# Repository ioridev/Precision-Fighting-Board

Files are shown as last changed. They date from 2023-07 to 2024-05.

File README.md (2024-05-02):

# [Precision-Fighting-Board](https://github.com/ioridev/Precision-Fighting-Board)
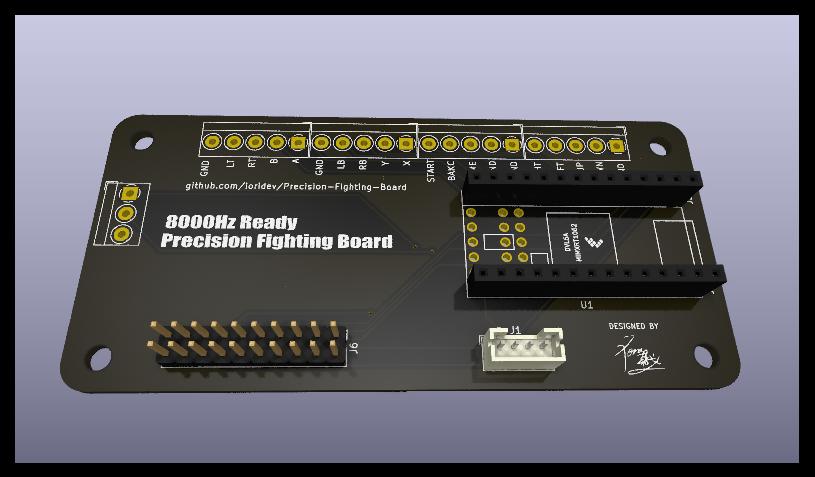
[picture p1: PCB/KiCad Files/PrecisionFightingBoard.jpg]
board


We all need to use this board in 20XX.  
[Discussions](https://github.com/ioridev/Precision-Fighting-Board/discussions)  
## Description

This project aims to develop the fastest game controller by utilizing the power of [Teensy 4.0](https://www.pjrc.com/store/teensy40.html). We strive to achieve a polling rate of 8000Hz, delivering unparalleled responsiveness for an immersive gaming experience.

## Where to Buy
Booth (https://iori-giken.booth.pm/)  
Available for purchase on Booth. Buying from this shop directly supports the developers. For international customers, shipping outside of Japan is possible using address forwarding services like Buyee and Tenso.  


[https://iori-giken.booth.pm/](https://iori-giken.booth.pm/)

## Features

- High-speed USB communication using [Teensy 4.0](https://www.pjrc.com/store/teensy40.html)
- Targeting an impressive 8000Hz polling rate
- Precise and instantaneous input response
- X-input support
- No waiting time for debounce

## Installation
Open the PrecisionFightingBoard.TEENSY40.hex file in [Teensyduino 1.53](https://www.pjrc.com/teensy/td_158/TeensyduinoInstall.exe) and write to [Teensy 4.0](https://www.pjrc.com/store/teensy40.html).　
| Pin Number | Button |
|---|---|
| 0 | Up |
| 1 | Down |
| 2 | Left |
| 3 | Right |
| 4 | Home |
| 5 | Back |
| 6 | Start |
| 7 | Y |
| 8 | X |
| 9 | RB |
| 10 | LB |
| 11 | A |
| 12 | B |
| 14 | RT |
| 15 | LT |
| 18 | L3 |
| 19 | R3 |


### Tips
Not good at soldering or making wires?  
Some models are equipped with pins from the beginning, so you can skip this complicated process by using this type of wire and wire for Brook.  
[Teensy 4.0 Pins](https://www.pjrc.com/store/teensy40_pins.html)

  
  
  


One GND with a pin is missing, so it must be branched with a breadboard or similar.　 

Or you can purchase Breakout Board on Amazon.  
  
[Breakout Board for Teensy 4.0](https://www.amazon.com/dp/B0C5SXFTC1?_encoding=UTF8&psc=1&ref_=cm_sw_r_cp_ud_dp_3P4ZTVVE18NE8B7TW8SG)

## Setting Up the Development Environment
Install Arduino IDE 1.8.13 and Teensyduino 1.53.

Clone this repository and copy the x-input/ArduinoXinput_Teensy/teensy directory to C:\Program Files (x86)\Arduino\hardware.

Open PrecisionFightingBoard.ino with the Arduino IDE, go to Tools, change the USB Type to XInput, and then upload it to the Teensy 4.0.

## Benchmark
### Polling rate test results 
I caught the continuous X-input button loop in my Python program and confirmed that it was around 0.125 ms.  
  
The program used for the test is in Precision-Fighting-Board/x-input/tester and anyone can try it out.

### Comparison with PicoBoard
tester/gamepad_response_time_comparison.py  
Gamepad 1 is a Precision-Fighting-Board.  
Gamepad 2 is a gp2040-ce  

  

### Comparison with Brook PS4+ Audio Fighting Board
Gamepad 1 is a Precision-Fighting-Board.  
Gamepad 2 is a Brook AFB  


### Use with WingmanFGC　
This is a test on a PC, but when used with WingmanFGC.  
Gamepad 1 is a Precision-Fighting-Board with WingmanFGC.  
Gamepad 2 is a gp2040-ce  
  
Good results with input lag of up to 5 ms.　　　

## Contributing

Contributions are welcome! If you'd like to contribute to this project, please follow these steps:

1. Fork the repository.
2. Create a new branch.
3. Make your enhancements or bug fixes.
4. Test thoroughly.
5. Submit a pull request detailing your changes.

## License

This project is licensed under the [MIT License](https://opensource.org/licenses/MIT). Please see the `LICENSE` file for more information.

## Acknowledgements

We would like to express our gratitude to the developers and contributors of Teency 4.0 for their amazing work and support.

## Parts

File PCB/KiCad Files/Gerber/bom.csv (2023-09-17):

Designator | Footprint | Quantity | Value | LCSC Part #
H1, H2, H3, H4 | MountingHole_3.5mm | 4 | MountingHole
J1 | JST_PH_B4B-PH-K_1x04_P2.00mm_Vertical | 1 | Conn_01x04_Male
J10, J7, J8, J9 | TerminalBlock_MetzConnect_Type059_RT06305HBWC_1x05_P3.50mm_Horizontal | 4 | ST01x05
J5 | TerminalBlock_MetzConnect_Type059_RT06303HBWC_1x03_P3.50mm_Horizontal | 1 | Screw_Terminal_01x03
J6 | PinHeader_2x10_P2.54mm_Vertical | 1 | Conn_02x10_Odd_Even
U1 | Teensy40 | 1 | Teensy4.0

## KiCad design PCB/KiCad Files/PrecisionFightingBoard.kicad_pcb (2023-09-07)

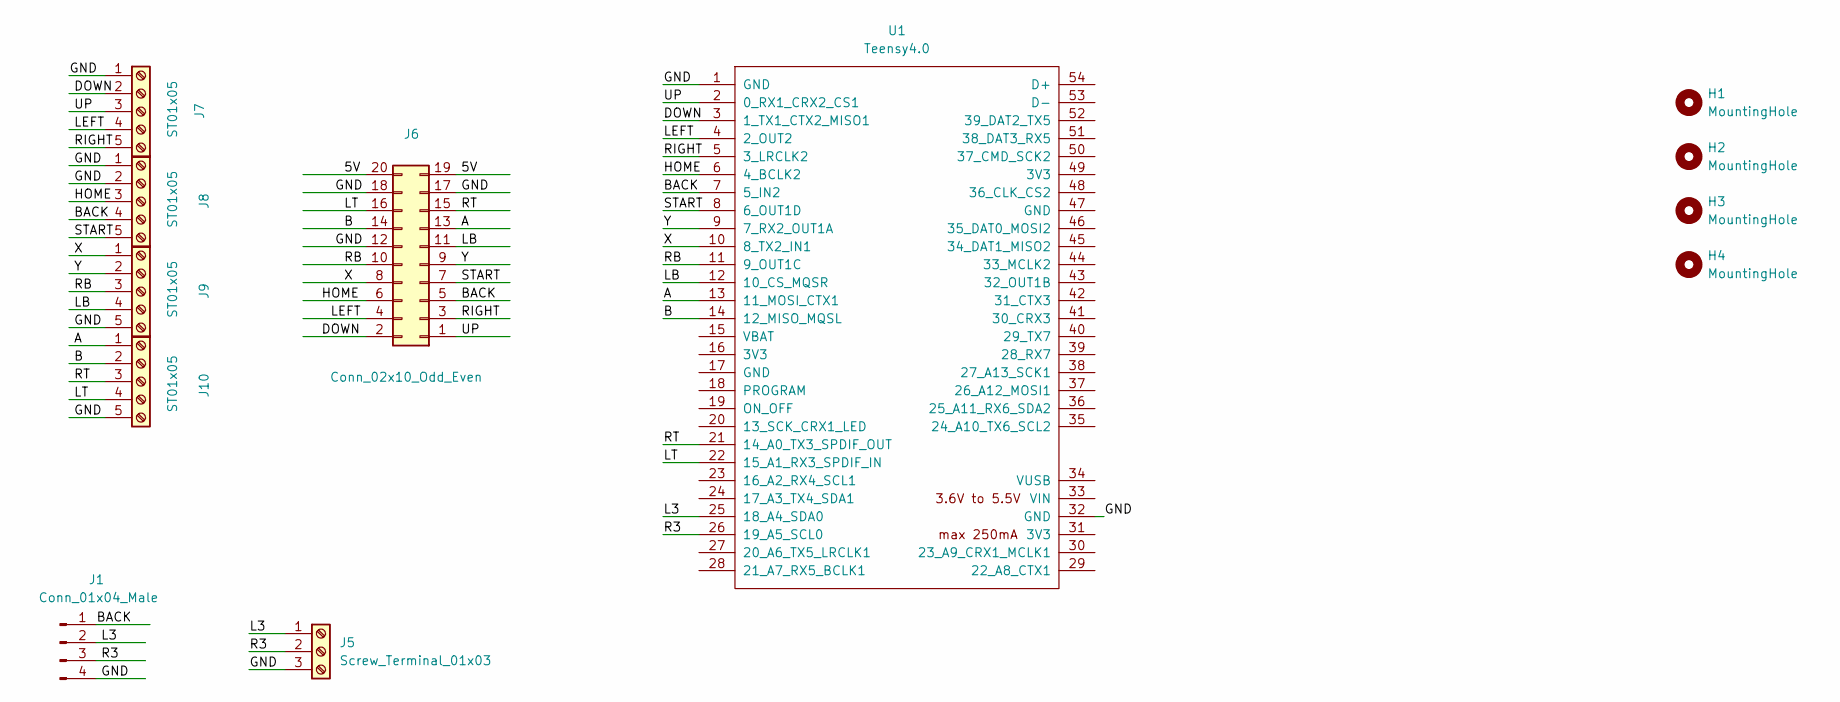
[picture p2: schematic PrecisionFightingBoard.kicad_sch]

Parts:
H1, H2, H3, H4: MountingHole; MountingHole_3.5mm
J1: Conn_01x04_Male; JST_PH_B4B-PH-K_1x04_P2.00mm_Vertical
J5: Screw_Terminal_01x03; TerminalBlock_MetzConnect_Type059_RT06303HBWC_1x03_P3.50mm_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
J6: Conn_02x10_Odd_Even; PinHeader_2x10_P2.54mm_Vertical
J7, J8, J9, J10: ST01x05; TerminalBlock_MetzConnect_Type059_RT06305HBWC_1x05_P3.50mm_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
U1: Teensy4.0; Teensy40

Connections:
/5V: J6.19, J6.20
/A: J6.13, J10.1, U1.13 (11_MOSI_CTX1)
/B: J6.14, J10.2, U1.14 (12_MISO_MQSL)
/BACK: J1.1, J6.5, J8.4, U1.7 (5_IN2)
/DOWN: J6.2, J7.2, U1.3 (1_TX1_CTX2_MISO1)
/GND: J1.4, J5.3, J6.12, J6.17, J6.18, J7.1, J8.1, J8.2, J9.5, J10.5, U1.1 (GND), U1.32 (GND)
/HOME: J6.6, J8.3, U1.6 (4_BCLK2)
/L3: J1.2, J5.1, U1.25 (18_A4_SDA0)
/LB: J6.11, J9.4, U1.12 (10_CS_MQSR)
/LEFT: J6.4, J7.4, U1.4 (2_OUT2)
/LT: J6.16, J10.4, U1.22 (15_A1_RX3_SPDIF_IN)
/R3: J1.3, J5.2, U1.26 (19_A5_SCL0)
/RB: J6.10, J9.3, U1.11 (9_OUT1C)
/RIGHT: J6.3, J7.5, U1.5 (3_LRCLK2)
/RT: J6.15, J10.3, U1.21 (14_A0_TX3_SPDIF_OUT)
/START: J6.7, J8.5, U1.8 (6_OUT1D)
/UP: J6.1, J7.3, U1.2 (0_RX1_CRX2_CS1)
/X: J6.8, J9.1, U1.10 (8_TX2_IN1)
/Y: J6.9, J9.2, U1.9 (7_RX2_OUT1A)

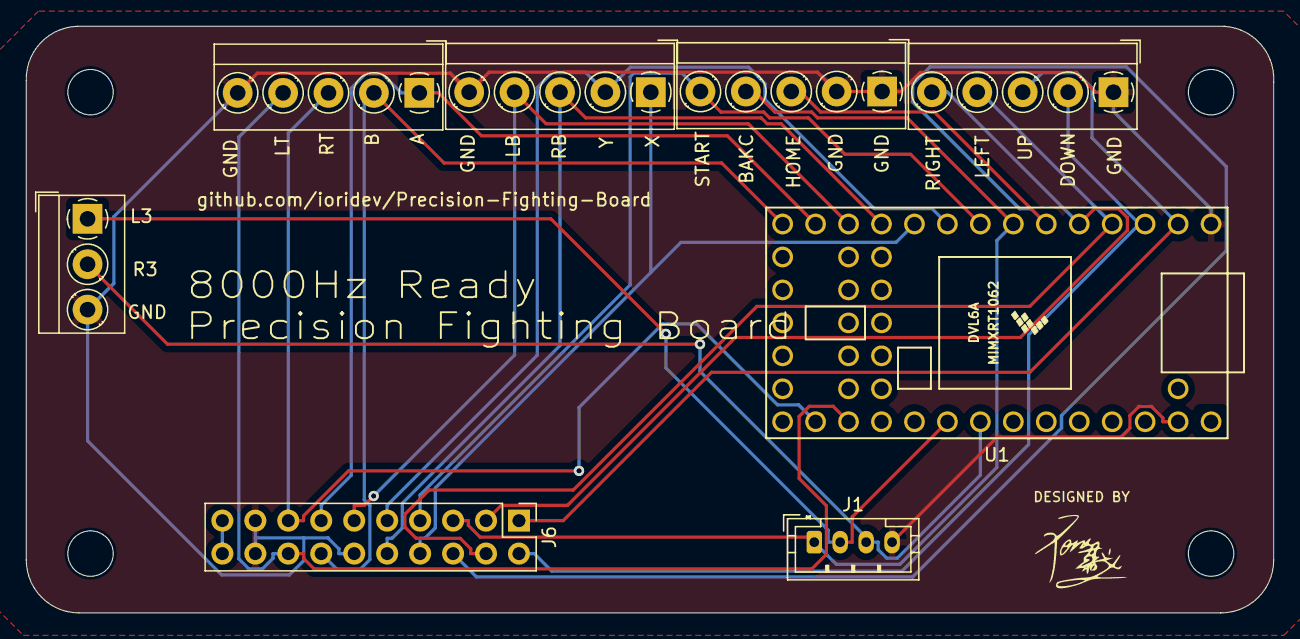
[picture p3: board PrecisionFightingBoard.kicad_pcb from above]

Board: 2 copper layers, 96.1 x 45.2 mm, 12 parts (0 on the bottom side), 19 nets.

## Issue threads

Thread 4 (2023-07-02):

The x-input Polling rate appears to be 1000 Hz.

ioridev, 2023-07-02:
Testing Xinput with tester.ino and tester.py　
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
Expected to be 125us

ioridev, 2023-07-03:
https://forum.pjrc.com/threads/63948-USB-2-0-Teensy-port-at-8000-Hz-poll-rate?p=328249#post328249

ioridev, 2023-07-03:
I used time.perf_counter() and it improved

ioridev, 2023-07-03:
The keyboard and joystick seem to be at 8000Hz, but the X-input is still close to 1000Hz.
Time difference: 850.1999969482422 μs
Key BTN_SOUTH 1
Time difference: 156.0999984741211 μs
Sync SYN_REPORT 0
Time difference: 848.5 μs
Key BTN_SOUTH 0
Time difference: 243.3000030517578 μs
Sync SYN_REPORT 0
Time difference: 744.6999969482422 μs
Key BTN_SOUTH 1
Time difference: 159.40000915527344 μs
Sync SYN_REPORT 0
Time difference: 846.3999938964844 μs
Key BTN_SOUTH 0
Time difference: 150.20000457763672 μs
Sync SYN_REPORT 0
Time difference: 849.3999938964844 μs
Key BTN_SOUTH 1
Time difference: 128.0 μs
Sync SYN_REPORT 0
Time difference: 865.9000015258789 μs
Key BTN_SOUTH 0
Time difference: 223.60000610351562 μs
Sync SYN_REPORT 0
Time difference: 782.9999923706055 μs
Key BTN_SOUTH 1
Time difference: 120.0999984741211 μs
Sync SYN_REPORT 0
Time difference: 863.7000045776367 μs
Key BTN_SOUTH 0
Time difference: 108.39999389648438 μs
Sync SYN_REPORT 0
Time difference: 895.0 μs
Key BTN_SOUTH 1
Time difference: 135.40000915527344 μs
Sync SYN_REPORT 0
Time difference: 869.0999908447266 μs
Key BTN_SOUTH 0
Time difference: 140.3000030517578 μs
Sync SYN_REPORT 0
Time difference: 868.8000030517578 μs
Key BTN_SOUTH 1
Time difference: 137.39999389648438 μs
Sync SYN_REPORT 0
Time difference: 853.8000030517578 μs
Key BTN_SOUTH 0
Time difference: 129.4000015258789 μs
Sync SYN_REPORT 0
Time difference: 878.1000061035156 μs
Key BTN_SOUTH 1
Time difference: 135.5999984741211 μs
Sync SYN_REPORT 0
Time difference: 862.2999954223633 μs

ioridev, 2023-07-03:
https://forum.pjrc.com/threads/73138-How-to-Achieve-8000Hz-with-a-Xinput-Controller-on-Teensy-4-0

ioridev, 2023-07-03:
d-input
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

ioridev, 2023-07-04:
https://github.com/ioridev/Precision-Fighting-Board/commit/17f14b289a24d682160661a9adb1336ac5efb217

Closed 2023-07-04.

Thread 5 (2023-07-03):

Strange results from x-ipunt polling rate test　

ioridev, 2023-07-03:
Run x-input/tester.ino and loop through button presses while x-input/tester.py takes data.

The expected value is around 125 µs, but the actual result is thus an alternating output of slow and fast values.　

```
Time difference: 79.7999997138977 μs
Time difference: 919.7000002861023 μs
Time difference: 95.49999976158142 μs
Time difference: 907.7000000476837 μs
Time difference: 76.59999990463257 μs
Time difference: 922.9000000953674 μs
Time difference: 102.0 μs
Time difference: 896.2999999523163 μs
Time difference: 90.29999995231628 μs
Time difference: 910.0 μs
Time difference: 88.10000014305115 μs
Time difference: 917.6000001430511 μs
Time difference: 83.69999980926514 μs
Time difference: 901.2999999523163 μs
Time difference: 75.70000004768372 μs
```
I wonder why, is there a problem with TestScript?　

ioridev, 2023-07-03:
https://github.com/ioridev/Precision-Fighting-Board/commit/54e1b2c6a36993159b87f3c438691f63e31fc755

Closed 2023-07-03.

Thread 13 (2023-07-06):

Saving user settings

ioridev, 2023-07-06:
Change polling rate or input mode and save

>Program / Flash Memory
Teensy 4.0 has 2 Mbyte of flash memory intended for storing your code. The flash memory can also store read-only variables and arrays. A portion of the flash memory may be used for file storage using the LittleFS library. The top 64K of this memory is reserved for EEPROM emulation data and the LED blink restore program.
https://www.pjrc.com/store/teensy40.html

ioridev, 2023-07-12:
I want to implement a web configurator.

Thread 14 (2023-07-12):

Console support?

ioridev, 2023-07-12:
I am trying to figure out if I should support the console.
Obviously this spec is geared towards PC users, so I don't think we should support consoles.
Also, there is no way to verify that the console is receiving 8000 Hz input.

ioridev, 2023-08-26:
https://github.com/ioridev/Precision-Fighting-Board/discussions/19

Closed 2023-08-26.

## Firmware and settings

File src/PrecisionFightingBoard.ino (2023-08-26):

#include <XInput.h>
#include <Bounce2.h>

const int Pin_ButtonA = 11;
const int Pin_ButtonB = 12;
const int Pin_ButtonX = 8;
const int Pin_ButtonY = 7;

const int Pin_ButtonLB = 10;
const int Pin_ButtonRB = 9;

const int Pin_ButtonBack = 5;
const int Pin_ButtonStart = 6;

const int Pin_ButtonL3 =  18;
const int Pin_ButtonR3 = 19;

const int Pin_DpadUp = 0;
const int Pin_DpadDown = 1;
const int Pin_DpadLeft = 2;
const int Pin_DpadRight = 3;

const int Pin_ButtonXbox = 4;

const int Pin_TriggerL = 14;
const int Pin_TriggerR = 15;

Bounce debouncerA = Bounce();
Bounce debouncerB = Bounce();
Bounce debouncerX = Bounce();
Bounce debouncerY = Bounce();

Bounce debouncerLB = Bounce();
Bounce debouncerRB = Bounce();

Bounce debouncerBack = Bounce();
Bounce debouncerStart = Bounce();

Bounce debouncerL3 = Bounce();
Bounce debouncerR3 = Bounce();

Bounce debouncerDpadUp = Bounce();
Bounce debouncerDpadDown = Bounce();
Bounce debouncerDpadLeft = Bounce();
Bounce debouncerDpadRight = Bounce();

Bounce debouncerTriggerL = Bounce();
Bounce debouncerTriggerR = Bounce();

Bounce debouncerXbox = Bounce();

void setup()
{
  pinMode(Pin_ButtonA, INPUT_PULLUP);
  pinMode(Pin_ButtonB, INPUT_PULLUP);
  pinMode(Pin_ButtonX, INPUT_PULLUP);
  pinMode(Pin_ButtonY, INPUT_PULLUP);

  pinMode(Pin_ButtonLB, INPUT_PULLUP);
  pinMode(Pin_ButtonRB, INPUT_PULLUP);

  pinMode(Pin_ButtonBack, INPUT_PULLUP);
  pinMode(Pin_ButtonStart, INPUT_PULLUP);

  pinMode(Pin_ButtonL3, INPUT_PULLUP);
  pinMode(Pin_ButtonR3, INPUT_PULLUP);

  pinMode(Pin_DpadUp, INPUT_PULLUP);
  pinMode(Pin_DpadDown, INPUT_PULLUP);
  pinMode(Pin_DpadLeft, INPUT_PULLUP);
  pinMode(Pin_DpadRight, INPUT_PULLUP);

  pinMode(Pin_TriggerL, INPUT_PULLUP);
  pinMode(Pin_TriggerR, INPUT_PULLUP);

pinMode(Pin_ButtonXbox, INPUT_PULLUP);

  debouncerA.attach(Pin_ButtonA);
  debouncerB.attach(Pin_ButtonB);
  debouncerX.attach(Pin_ButtonX);
  debouncerY.attach(Pin_ButtonY);

  debouncerLB.attach(Pin_ButtonLB);
  debouncerRB.attach(Pin_ButtonRB);

  debouncerBack.attach(Pin_ButtonBack);
  debouncerStart.attach(Pin_ButtonStart);

  debouncerL3.attach(Pin_ButtonL3);
  debouncerR3.attach(Pin_ButtonR3);

  debouncerDpadUp.attach(Pin_DpadUp);
  debouncerDpadDown.attach(Pin_DpadDown);
  debouncerDpadLeft.attach(Pin_DpadLeft);
  debouncerDpadRight.attach(Pin_DpadRight);

  debouncerTriggerL.attach(Pin_TriggerL);
  debouncerTriggerR.attach(Pin_TriggerR);

  debouncerXbox.attach(Pin_ButtonXbox);


  debouncerA.interval(3);
  debouncerB.interval(3);
  debouncerX.interval(3);
  debouncerY.interval(3);

  debouncerLB.interval(3);
  debouncerRB.interval(3);

  debouncerBack.interval(3);
  debouncerStart.interval(3);

  debouncerL3.interval(3);
  debouncerR3.interval(3);

  debouncerDpadUp.interval(3);
  debouncerDpadDown.interval(3);
  debouncerDpadLeft.interval(3);
  debouncerDpadRight.interval(3);

  debouncerTriggerL.interval(3);
  debouncerTriggerR.interval(3);

debouncerXbox.interval(3);

  XInput.setAutoSend(false);
  XInput.begin();
}

void loop()
{
  debouncerA.update();
  debouncerB.update();
  debouncerX.update();
  debouncerY.update();

  debouncerLB.update();
  debouncerRB.update();

  debouncerBack.update();
  debouncerStart.update();

  debouncerL3.update();
  debouncerR3.update();

  debouncerDpadUp.update();
  debouncerDpadDown.update();
  debouncerDpadLeft.update();
  debouncerDpadRight.update();

  debouncerTriggerL.update();
  debouncerTriggerR.update();

  debouncerXbox.update();

  boolean buttonA = !debouncerA.read();
  boolean buttonB = !debouncerB.read();
  boolean buttonX = !debouncerX.read();
  boolean buttonY = !debouncerY.read();

  boolean buttonLB = !debouncerLB.read();
  boolean buttonRB = !debouncerRB.read();

  boolean buttonBack = !debouncerBack.read();
  boolean buttonStart = !debouncerStart.read();

  boolean buttonL3 = !debouncerL3.read();
  boolean buttonR3 = !debouncerR3.read();

  boolean dpadUp = !debouncerDpadUp.read();
  boolean dpadDown = !debouncerDpadDown.read();
  boolean dpadLeft = !debouncerDpadLeft.read();
  boolean dpadRight = !debouncerDpadRight.read();

  boolean buttonXbox = !debouncerXbox.read();

  // SOCD Cleaning
  if (dpadRight && dpadLeft)
  {
    dpadRight = false;
    dpadLeft = false;
  }

  if (dpadUp && dpadDown)
  {
    dpadUp = false;
    dpadDown = false;
  }

  XInput.setButton(BUTTON_A, buttonA);
  XInput.setButton(BUTTON_B, buttonB);
  XInput.setButton(BUTTON_X, buttonX);
  XInput.setButton(BUTTON_Y, buttonY);

  XInput.setButton(BUTTON_LB, buttonLB);
  XInput.setButton(BUTTON_RB, buttonRB);

  XInput.setButton(BUTTON_BACK, buttonBack);
  XInput.setButton(BUTTON_START, buttonStart);

  XInput.setButton(BUTTON_L3, buttonL3);
  XInput.setButton(BUTTON_R3, buttonR3);

  XInput.setDpad(dpadUp, dpadDown, dpadLeft, dpadRight);

  boolean triggerLeft = !debouncerTriggerL.read();
  boolean triggerRight = !debouncerTriggerR.read();

  XInput.setButton(TRIGGER_LEFT, triggerLeft);
  XInput.setButton(TRIGGER_RIGHT, triggerRight);

  XInput.setButton(BUTTON_LOGO, buttonXbox);

  XInput.send();
}

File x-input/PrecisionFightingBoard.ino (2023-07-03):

#include <XInput.h>

const int Pin_ButtonA = 0;
const int Pin_ButtonB = 1;
const int Pin_ButtonX = 2;
const int Pin_ButtonY = 3;

const int Pin_ButtonLB = 4;
const int Pin_ButtonRB = 5;

const int Pin_ButtonBack = 6;
const int Pin_ButtonStart = 7;

const int Pin_ButtonL3 = 8;
const int Pin_ButtonR3 = 9;

const int Pin_DpadUp = 10;
const int Pin_DpadDown = 11;
const int Pin_DpadLeft = 12;
const int Pin_DpadRight = 13;

const int Pin_TriggerL = A4;
const int Pin_TriggerR = A5;

void setup()
{

  pinMode(Pin_TriggerL, INPUT_PULLUP);
  pinMode(Pin_TriggerR, INPUT_PULLUP);

  pinMode(Pin_ButtonA, INPUT_PULLUP);
  pinMode(Pin_ButtonB, INPUT_PULLUP);
  pinMode(Pin_ButtonX, INPUT_PULLUP);
  pinMode(Pin_ButtonY, INPUT_PULLUP);

  pinMode(Pin_ButtonLB, INPUT_PULLUP);
  pinMode(Pin_ButtonRB, INPUT_PULLUP);

  pinMode(Pin_ButtonBack, INPUT_PULLUP);
  pinMode(Pin_ButtonStart, INPUT_PULLUP);

  pinMode(Pin_ButtonL3, INPUT_PULLUP);
  pinMode(Pin_ButtonR3, INPUT_PULLUP);

  pinMode(Pin_DpadUp, INPUT_PULLUP);
  pinMode(Pin_DpadDown, INPUT_PULLUP);
  pinMode(Pin_DpadLeft, INPUT_PULLUP);
  pinMode(Pin_DpadRight, INPUT_PULLUP);

  XInput.setAutoSend(false);

  XInput.begin();
}

void loop()
{
  boolean buttonA = !digitalRead(Pin_ButtonA);
  boolean buttonB = !digitalRead(Pin_ButtonB);
  boolean buttonX = !digitalRead(Pin_ButtonX);
  boolean buttonY = !digitalRead(Pin_ButtonY);

  boolean buttonLB = !digitalRead(Pin_ButtonLB);
  boolean buttonRB = !digitalRead(Pin_ButtonRB);

  boolean buttonBack = !digitalRead(Pin_ButtonBack);
  boolean buttonStart = !digitalRead(Pin_ButtonStart);

  boolean buttonL3 = !digitalRead(Pin_ButtonL3);
  boolean buttonR3 = !digitalRead(Pin_ButtonR3);

  boolean dpadUp = !digitalRead(Pin_DpadUp);
  boolean dpadDown = !digitalRead(Pin_DpadDown);
  boolean dpadLeft = !digitalRead(Pin_DpadLeft);
  boolean dpadRight = !digitalRead(Pin_DpadRight);

  XInput.setButton(BUTTON_A, buttonA);
  XInput.setButton(BUTTON_B, buttonB);
  XInput.setButton(BUTTON_X, buttonX);
  XInput.setButton(BUTTON_Y, buttonY);

  XInput.setButton(BUTTON_LB, buttonLB);
  XInput.setButton(BUTTON_RB, buttonRB);

  XInput.setButton(BUTTON_BACK, buttonBack);
  XInput.setButton(BUTTON_START, buttonStart);

  XInput.setButton(BUTTON_L3, buttonL3);
  XInput.setButton(BUTTON_R3, buttonR3);

  XInput.setDpad(dpadUp, dpadDown, dpadLeft, dpadRight);

  boolean triggerLeft = !digitalRead(Pin_TriggerL);
  boolean triggerRight = !digitalRead(Pin_TriggerR);

  XInput.setButton(TRIGGER_LEFT, triggerLeft);
  XInput.setButton(TRIGGER_RIGHT, triggerRight);

  XInput.send();
}

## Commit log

2023-07-02 add buttons
2023-07-02 fix d-input test program
    [tester.ino]
2023-07-03 fix using pin
2023-07-03 add ArduinoXInput_Teensy
2023-07-03 fix pin
2023-07-03 set xinput 8000Hz
2023-07-03 set 8000hz
2023-07-03 Make button pins easy to recognize.
2023-07-04 Update handle button bounce
2023-07-05 Refactor PrecisionFightingBoard.TEENSY40.hex for improved performance
2023-07-05 Optimize code for PrecisionFightingBoard.TEENSY40.hex file.
2023-07-05 Refactor button debouncing code for improved responsiveness.
2023-07-05 Improve precision in board's firmware.
2023-08-08 add xbox button
2023-08-14 Revert "Merge pull request #16 from ioridev/add-homebutton"
    This reverts commit 0dd978a9f9cbb1a6a3a684d407d885486a9675fa, reversing
    changes made to 9f3a0dc22b2472b0e3af3778b5d182da007d6032.
    [PrecisionFightingBoard.ino]
2023-08-15 Revert "Revert "Merge pull request #16 from ioridev/add-homebutton""
    This reverts commit 1d300ed75660a2c9f941322a448a5569e7e30e9e.
    [PrecisionFightingBoard.ino]
2023-08-20 add PCB
    [Teensy.kicad_pcb, Teensy.kicad_sch]
2023-08-20 add mounting hole
    [PrecisionFightingBoard.kicad_sch]
2023-08-20 Create a schematic
    [PrecisionFightingBoard.kicad_sch]
2023-08-20 add GND wire
    [PrecisionFightingBoard.kicad_sch]
2023-08-23 add connector
    [PrecisionFightingBoard.kicad_sch]
2023-08-23 Update button mappings in README file
2023-08-24 create PCB
    [PrecisionFightingBoard.kicad_pcb, PrecisionFightingBoard.kicad_sch]
2023-08-25 add gerber files
    [PrecisionFightingBoard-B_Cu.gbr, PrecisionFightingBoard-B_Mask.gbr, PrecisionFightingBoard-B_Paste.gbr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]
2023-08-26 update pcb
    [PrecisionFightingBoard.kicad_pcb]
2023-08-29 Added rounded corners to the edges of the outline
    [PrecisionFightingBoard.kicad_pcb]
2023-08-29 Changed 4-pin screw terminal to 3-pin.
    [PrecisionFightingBoard.kicad_pcb, PrecisionFightingBoard.kicad_sch]
2023-08-29 Updated wiring.
    [PrecisionFightingBoard.dsn, PrecisionFightingBoard.kicad_pcb, PrecisionFightingBoard.kicad_sch]
2023-08-29 add label
    [PrecisionFightingBoard.kicad_pcb]
2023-09-07 fix pcb
    [PrecisionFightingBoard.kicad_pcb, PrecisionFightingBoard.kicad_sch]
2023-09-17 add gerber pos bom files
    [PrecisionFightingBoard-B_Cu.gbr, PrecisionFightingBoard-B_Mask.gbr, PrecisionFightingBoard-B_Paste.gbr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]
2025-09-25 .vscode/extensions.json と platformio.ini を削除
